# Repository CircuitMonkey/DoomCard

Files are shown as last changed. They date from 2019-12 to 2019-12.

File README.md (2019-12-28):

# DoomCard
Doom keycard themed PCB

I created a key card styled business card which is insprired by the Door Key Cards found in the original Doom game.

* Features
  * Measures 80mm long x 50mm high.
  * Uses 0402 size parts for a good SMT soldering challenge.
  * Adding recommended components will allow it to run as an Arduino Leonardo clone.
  * All Arduino pins route to a pad.
  * Includes spots for three WS2812B (3535-size) LEDs. Wired from SCK line.
  * Open Source!  Modify and embelish as desired.
  * Made with Eagle CAD

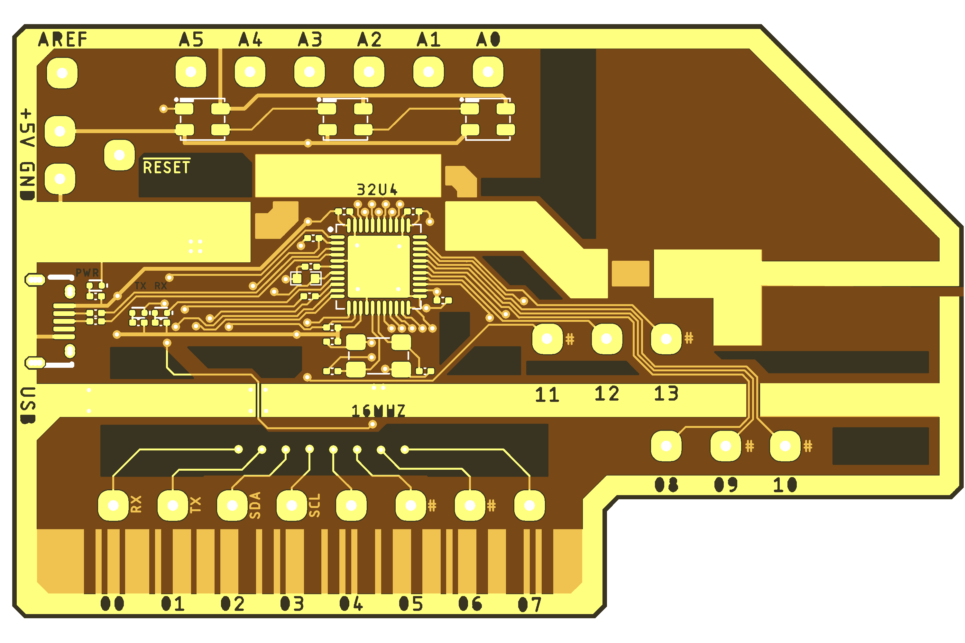
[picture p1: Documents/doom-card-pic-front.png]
Front View


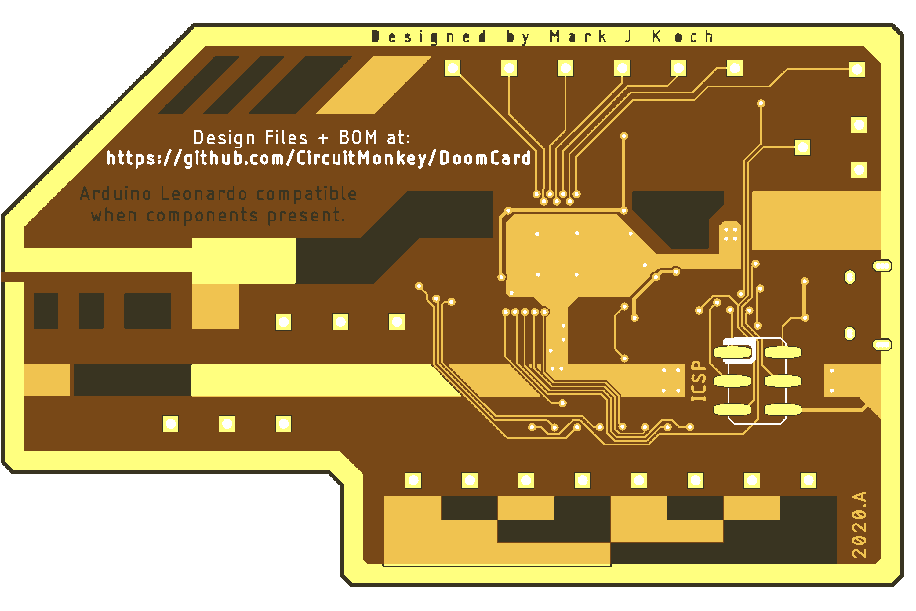
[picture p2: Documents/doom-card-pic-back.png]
Back View


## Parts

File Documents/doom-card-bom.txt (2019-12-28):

Partlist DoomCard Rev. A

Part   Value          Device                     Package              Description               MFR MPN
16MHZ  16MHz          SMD-4P3X5                  ABRACON_ABM3C        Crystal
32U4   32u4           ATMEGA32U4                 QFN-44               ATMEGA 32U4
C1     1uF            CAPACITOR0402              0402-CAP             Capacitor  CAP
C2     0.1uF          CAPACITOR0402              0402-CAP             Capacitor  CAP
C3     1uF            CAPACITOR0402              0402-CAP             Capacitor  CAP
C4     0.1uF          CAPACITOR0402              0402-CAP             Capacitor  CAP
C5     0.1uF          CAPACITOR0402              0402-CAP             Capacitor  CAP
C6     0.1uF          CAPACITOR0402              0402-CAP             Capacitor  CAP
C7     10uF           CAPACITOR0603              0603-CAP             Capacitor  CAP
C8     12pF           CAPACITOR0402              0402-CAP             Capacitor  CAP
C9     12pF           CAPACITOR0402              0402-CAP             Capacitor  CAP
ICSP   HEADER         CON_03X2-VT_SMD            MA03X2-VT-SMD        Header, 3x2 (6-pin), SMT
PX0    WS2812         SMART_LED3535              SMD_3535             Smart LED  SK6812  WS2812
PX1    WS2812         SMART_LED3535              SMD_3535             Smart LED  SK6812  WS2812
PX2    WS2812         SMART_LED3535              SMD_3535             Smart LED  SK6812  WS2812
R1     10K            RESISTOR0402               0402-RES             Resistor
R2     22R            RESISTOR0402               0402-RES             Resistor
R3     22R            RESISTOR0402               0402-RES             Resistor
R4     10K            RESISTOR0402               0402-RES             Resistor
R5     10K            RESISTOR0402               0402-RES             Resistor
R6     10K            RESISTOR0402               0402-RES             Resistor
R7     300            RESISTOR0402               0402-RES             Resistor
PWR    GREEN          SMT0402                    SMD_0402             LED SMT
RX     GREEN          SMT0402                    SMD_0402             LED SMT
TX     BLUE           SMT0402                    SMD_0402             LED SMT
USB    USB Micro-B    USB-B-MICRO-SMTJAE-DX4R005 JAE-DX4R005          USB Micro - B-style      JAE DX4R005JJ2R1800 https://www.mouser.com/ProductDetail/DX4R005JJ2R1800

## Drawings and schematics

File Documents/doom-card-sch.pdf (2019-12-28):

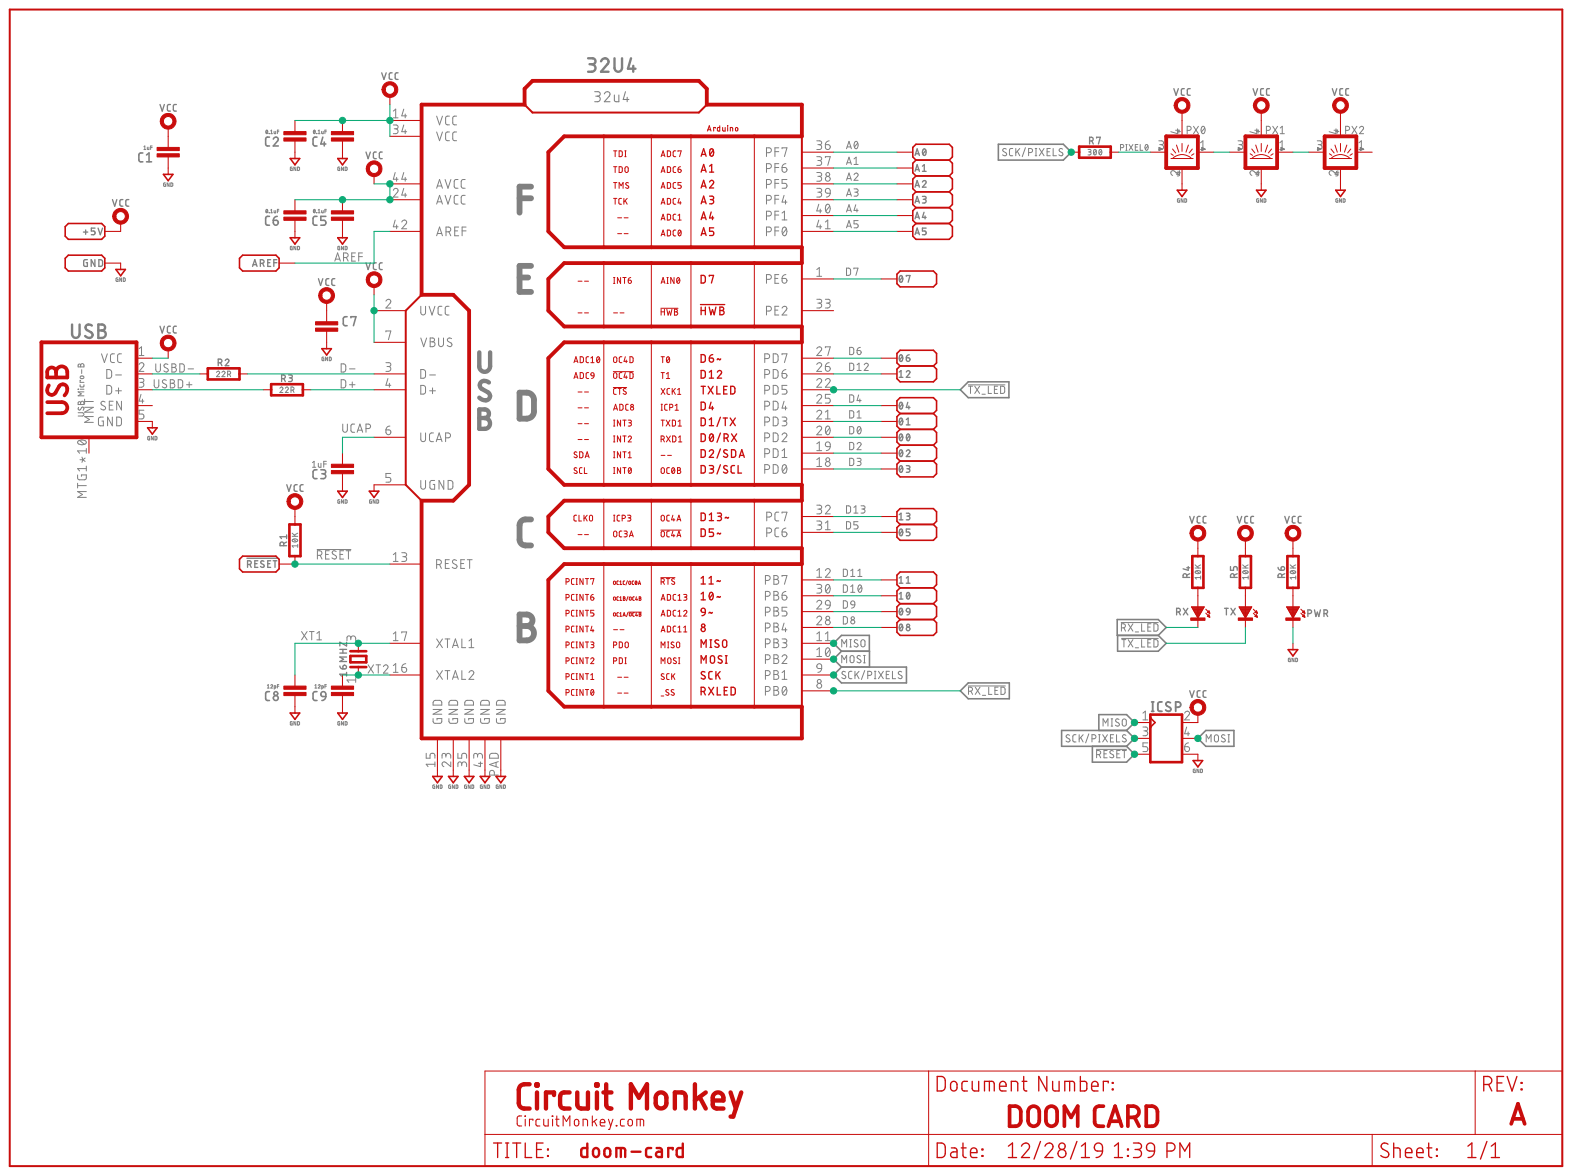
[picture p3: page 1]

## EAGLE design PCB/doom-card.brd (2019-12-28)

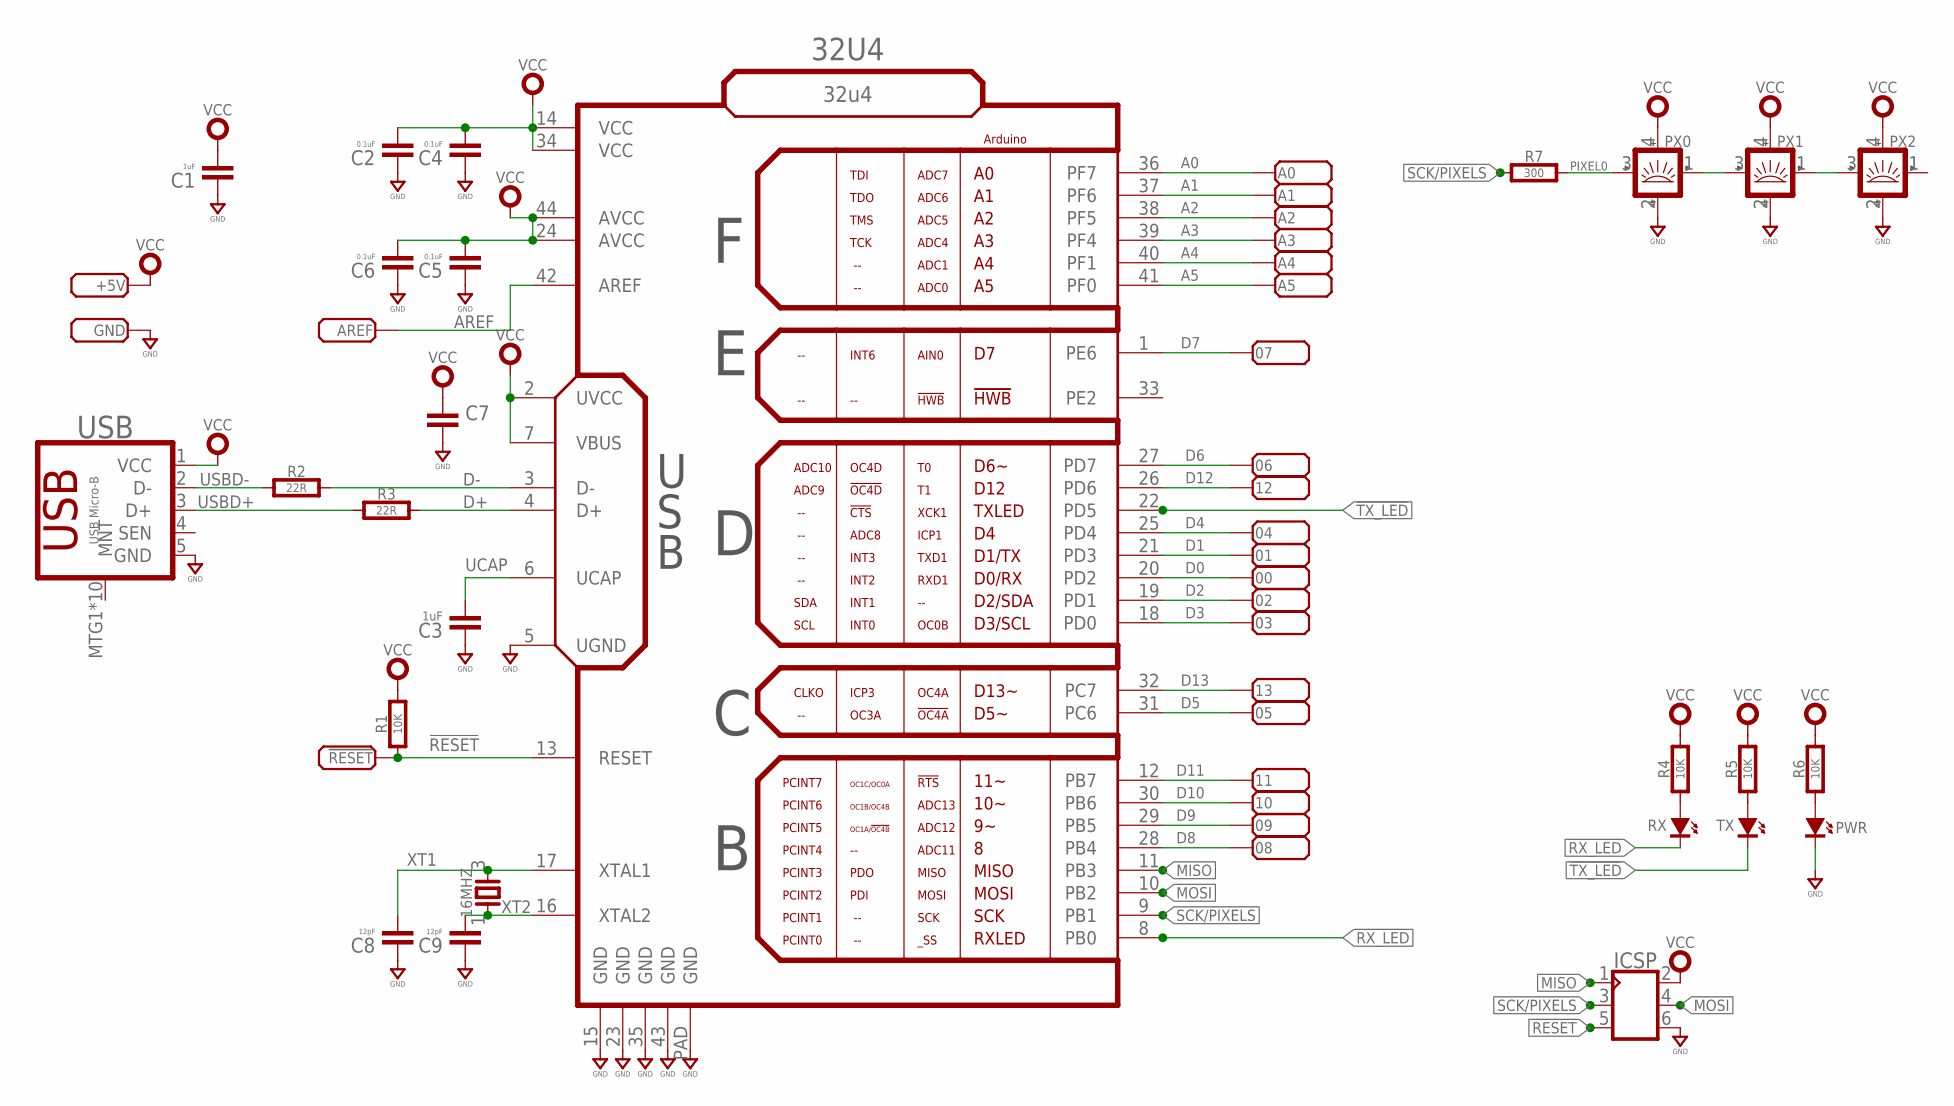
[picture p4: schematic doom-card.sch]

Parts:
00, 01, 02, 03, 04, 05, 06, 07, 08, 09, 10, 11, 12, 13: PADSMD-100X100; SMD-100X100
16MHZ: SMD-4P3X5; ABRACON_ABM3C
32U4: 32u4; QFN50P700X700X100-44
!RESET: PADSMD-100X100; SMD-100X100
+5V: PADSMD-100X100; SMD-100X100
A0, A1, A2, A3, A4, A5: PADSMD-100X100; SMD-100X100
AREF: PADSMD-100X100; SMD-100X100
C1, C3: 1uF; 0402-CAP
C2, C4, C5, C6: 0.1uF; 0402-CAP
C7: CAPACITOR0603; 0603-CAP
C8, C9: 12pF; 0402-CAP
GND: PADSMD-100X100; SMD-100X100
ICSP: CON_03X2-VT_SMD; MA03X2-VT-SMD
PWR: SMT0402; SMD_0402
PX0, PX1, PX2: SMART_LED3535; SMD_3535
R1, R4, R5, R6: 10K; 0402-RES
R2, R3: 22R; 0402-RES
R7: 300; 0402-RES
RX: SMT0402; SMD_0402
TX: SMT0402; SMD_0402
USB: USB Micro-B; JAE-DX4R005

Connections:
!RESET: 32U4.13 (RESET), !RESET.PAD, ICSP.5, R1.1
!RX_LED: 32U4.8 (PB0), RX.K (C)
!TX_LED: 32U4.22 (PD5), TX.K (C)
A0: 32U4.36 (PF7), A0.PAD
A1: 32U4.37 (PF6), A1.PAD
A2: 32U4.38 (PF5), A2.PAD
A3: 32U4.39 (PF4), A3.PAD
A4: 32U4.40 (PF1), A4.PAD
A5: 32U4.41 (PF0), A5.PAD
AREF: 32U4.42 (AREF), AREF.PAD
D0: 00.PAD, 32U4.20 (PD2)
D1: 01.PAD, 32U4.21 (PD3)
D2: 02.PAD, 32U4.19 (PD1)
D3: 03.PAD, 32U4.18 (PD0)
D4: 04.PAD, 32U4.25 (PD4)
D5: 05.PAD, 32U4.31 (PC6)
D6: 06.PAD, 32U4.27 (PD7)
D7: 07.PAD, 32U4.1 (PE6)
D8: 08.PAD, 32U4.28 (PB4)
D9: 09.PAD, 32U4.29 (PB5)
D10: 10.PAD, 32U4.30 (PB6)
D11: 11.PAD, 32U4.12 (PB7)
D12: 12.PAD, 32U4.26 (PD6)
D13: 13.PAD, 32U4.32 (PC7)
D+: 32U4.4 (D+), R3.2
D-: 32U4.3 (D-), R2.2
GND: 16MHZ.2 (GND), 16MHZ.4 (GND), 32U4.5 (UGND), 32U4.15 (GND), 32U4.23 (GND), 32U4.35 (GND), 32U4.43 (GND), 32U4.PAD (GND), C1.1, C2.1, C3.1, C4.1, C5.1, C6.1, C7.2, C8.1, C9.1, GND.PAD, ICSP.6, PWR.K (C), PX0.2 (GND), PX1.2 (GND), PX2.2 (GND), USB.5 (GND)
MISO: 32U4.11 (PB3), ICSP.1
MOSI: 32U4.10 (PB2), ICSP.4
unnamed: R4.1, RX.A
unnamed: R5.1, TX.A
unnamed: PWR.A, R6.1
unnamed: PX0.1 (OUT), PX1.3 (IN)
unnamed: PX1.1 (OUT), PX2.3 (IN)
PIXEL0: PX0.3 (IN), R7.2
SCK/PIXELS: 32U4.9 (PB1), ICSP.3, R7.1
UCAP: 32U4.6 (UCAP), C3.2
USBD+: R3.1, USB.3 (D+)
USBD-: R2.1, USB.2 (D-)
VCC: 32U4.2 (UVCC), 32U4.7 (VBUS), 32U4.14 (VCC), 32U4.24 (AVCC), 32U4.34 (VCC), 32U4.44 (AVCC), +5V.PAD, C1.2, C2.2, C4.2, C5.2, C6.2, C7.1, ICSP.2, PX0.4 (VDD), PX1.4 (VDD), PX2.4 (VDD), R1.2, R4.2, R5.2, R6.2, USB.1 (VCC)
XT1: 16MHZ.3, 32U4.17 (XTAL1), C8.2
XT2: 16MHZ.1, 32U4.16 (XTAL2), C9.2

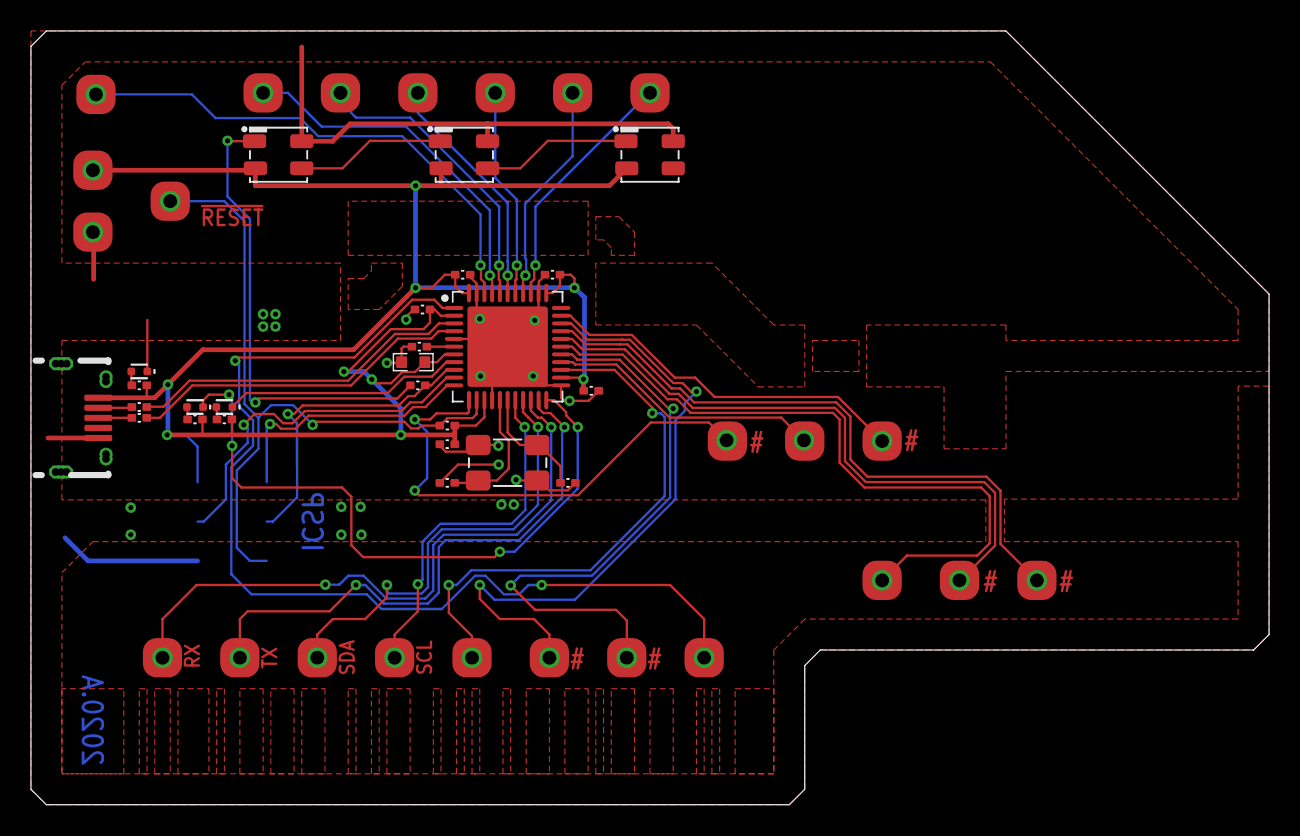
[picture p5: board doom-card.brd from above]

Board: 2 copper layers, 80.0 x 50.0 mm, 50 parts (1 on the bottom side), 42 nets.

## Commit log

2019-12-28 First Rev of Doom Card
    [doom-card.brd, doom-card.sch]
2019-12-28 Update schematic rev info
    Added screen shots of front and back.
    [doom-card.sch]
